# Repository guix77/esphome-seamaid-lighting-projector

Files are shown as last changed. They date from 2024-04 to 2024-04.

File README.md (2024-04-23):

# ESPHome remote for SeaMAID lighting projector

## Features

+ Turn on / off the light
+ Change the lightning mode

## Hardware

+ D1 mini ESP8266
+ stx882 (433Mhz transmitter)

Connect:
+ D1 ground to stx ground
+ D1 5V to stx VIN
+ D1 D4 (GPI02) to stx DATA

## Software

Create a new ESPHome with the following code: [pool-light.yaml](pool-light.yaml) 

## Case

### Box

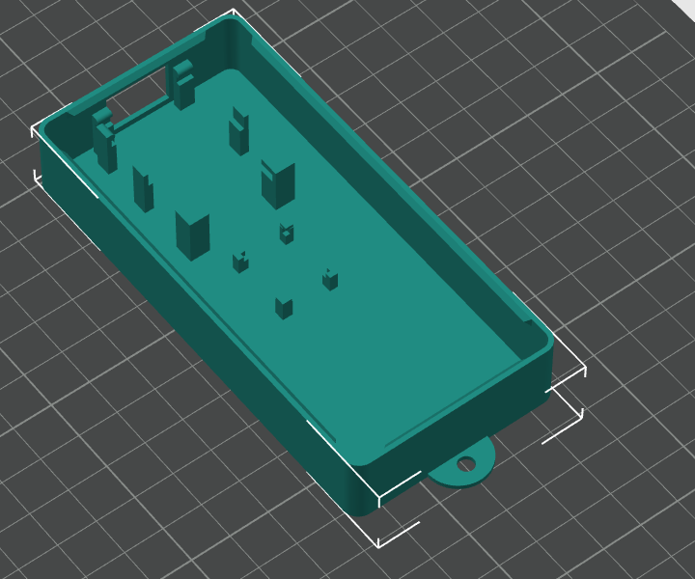
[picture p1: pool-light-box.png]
pool-light-box


[pool-light-box.stl](pool-light-box.stl)

In the box, the big mount is for the ESP and the small for the stx.

### Top

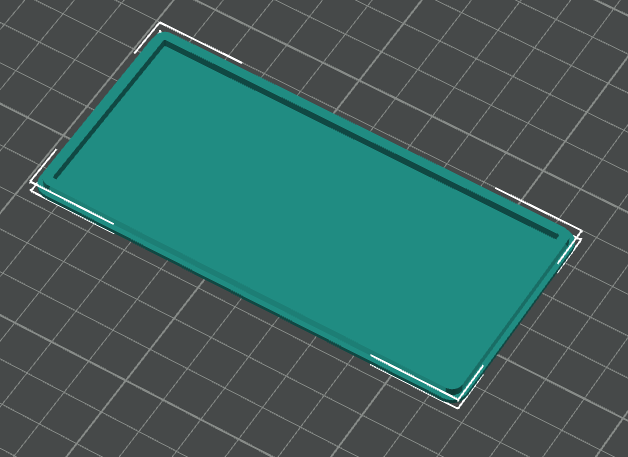
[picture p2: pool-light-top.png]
pool-light-top


[pool-light-top.stl](pool-light-top.stl)

### Photo

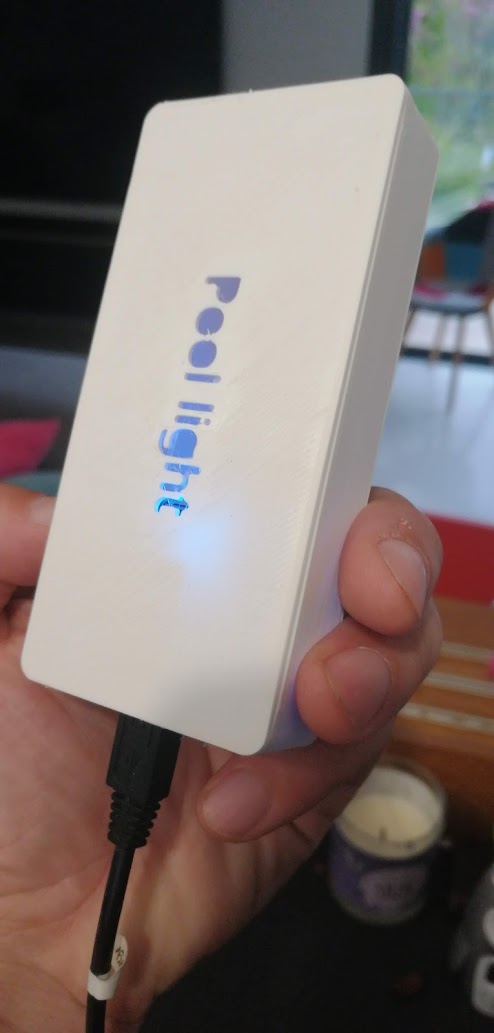
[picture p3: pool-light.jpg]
pool-light


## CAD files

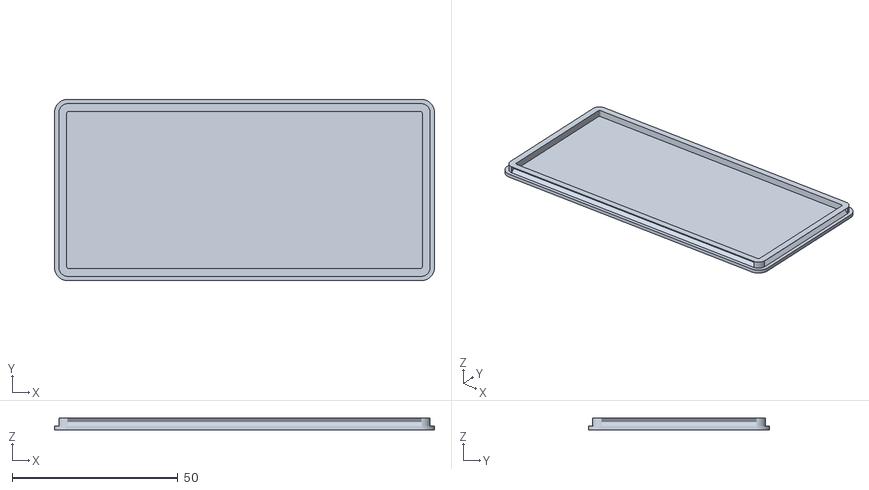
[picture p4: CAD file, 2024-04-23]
pool-light-top.stl
114.8 x 54.8 x 3.60

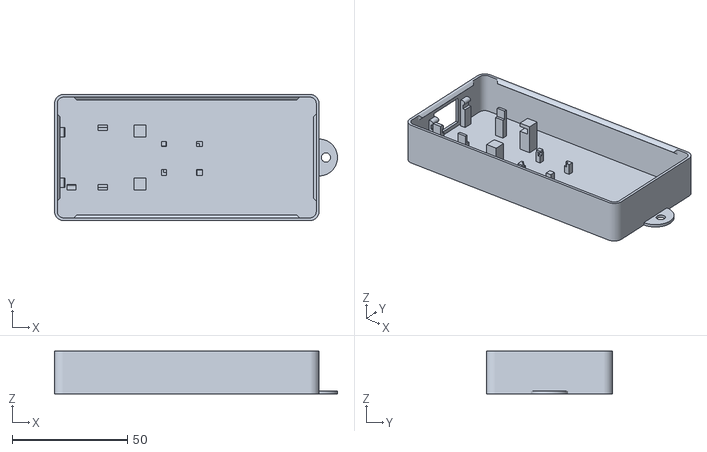
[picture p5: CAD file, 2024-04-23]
pool-light-box.stl
122.8 x 54.8 x 18.6

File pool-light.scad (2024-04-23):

use <ESPModels.scad>
use <sensorClip.scad>
use <wemos_d1_mini_clip.scad>

wemos_d1_offset = 10;
sensorWidth = 12;
sensorLength = 15;


// Which one would you like to see?
//part = "both"; // [box:Box only, top: Top cover only, both: Box and top cover]
part = "box";

// Size of your printer's nozzle in mm
nozzle_size = 0.4;

// Number of walls the print should have
number_of_walls = 3; // [1:5]

// Tolerance (use 0.2 for FDM)
tolerance = 0.2; // [0.1:0.1:0.4]

// Outer x dimension in mm
x=110+2*number_of_walls*nozzle_size+2*3*nozzle_size;

// Outer y dimension in mm
y=50+2*number_of_walls*nozzle_size+2*3*nozzle_size;

// Outer z dimension in mm
z=15+2*number_of_walls*nozzle_size+2*3*nozzle_size;

// Radius for rounded corners in mm
radius=4; // [1:20]

/* Hidden */
$fn=100;

wall_thickness=nozzle_size*number_of_walls;
hook_thickness = 3*nozzle_size;

top_cover_wall_thickness = hook_thickness + wall_thickness;

module bottom_box () {
    difference(){
        // Solid box
        linear_extrude(z-wall_thickness){
            minkowski(){
                square([x-radius*2,y-radius*2], center=true);
                circle(radius);
            }
        }
        
        // Hollow out
        translate([0,0,wall_thickness]) linear_extrude(z){
            minkowski(){
                square([x-radius*2-wall_thickness*2+wall_thickness*2,y-radius*2-wall_thickness*2+wall_thickness*2], center=true);
                circle(radius-wall_thickness);
            }
        }
        translate([-45, 11.5, 10]) {
            rotate([0, 0, -90]) {
                //WemosD1M(pins = 0, atorg = 2);
                translate([0, -6/2,2.5]) {
                    WemosD1M_USBLocate(atorg = 2)
                    translate([0, 6/2, 2.5]) {
                        cube([6.87+10, 6, 1.85+10], center=true);
                    }
                }
            }
        }
    }
    // D1 mini model.
    translate([-45, 11.5, 10]) {
        rotate([0, 0, -90]) {
            //WemosD1M(pins = 0, atorg = 2);
        }
    }
    // D1 mini clips.
    translate([-19, 13, wemos_d1_offset]) {
        rotate([0, 0, 180]) {
            wemos_d1_mini_clip(offset = wemos_d1_offset);
        }
    }
    // Sensor clip.
    translate([-11, 7, 0]) {
        rotate([0, 0, -90]) {
            sensorClip(sensorWidth, sensorLength, wall_thickness, 0.5);
        }
    }
    left_hook(); // left hook
    rotate([180,180,0]) left_hook(); // right hook
    front_hook(); // front hook
    rotate([180,180,0]) front_hook(); // back hook
    // TODO: hooks on the other two sides
    // Fixation.
    translate([x / 2, 0, 0]) {
        difference() {
            cylinder(h = wall_thickness, r = 8);
            translate([3, 0, 0]) {
                cylinder(h = wall_thickness + 0.01, r = 2);
            }
        }
    }
}

module left_hook () {
    
    translate([(x-2*wall_thickness)/2,-y/2+radius*2,z-wall_thickness]) rotate([0,90,90]) {
        difference(){
            linear_extrude(y-2*radius*2){
    polygon(points=[[0,0],[2*hook_thickness,0],[hook_thickness,hook_thickness]]);
        }
             translate([hook_thickness, hook_thickness, 0]) rotate([45,0,0]) cube(2*hook_thickness, center=true);
             translate([hook_thickness, hook_thickness, y-2*radius*2]) rotate([45,0,0]) cube(2*hook_thickness, center=true);        
        }
    }
}
    

module front_hook () {
    translate([(-x+4*radius)/2,-y/2+wall_thickness,z-wall_thickness]) rotate([90,90,90]) {
        difference(){
        linear_extrude(x-2*radius*2){
    polygon(points=[[0,0],[2*hook_thickness,0],[hook_thickness,hook_thickness]]);
    }
             translate([hook_thickness, hook_thickness, 0]) rotate([45,0,0]) cube(2*hook_thickness, center=true);
             translate([hook_thickness, hook_thickness, x-2*radius*2]) rotate([45,0,0]) cube(2*hook_thickness, center=true);
        }
    }
}


module right_grove () {
    translate([-tolerance/2+(x-2*wall_thickness)/2,-y/2+radius,wall_thickness+hook_thickness*2]) rotate([0,90,90]) linear_extrude(y-2*radius){
    polygon(points=[[0,0],[2*hook_thickness,0],[hook_thickness,hook_thickness]]);
    }
}


module front_grove () {
    translate([(-x+2*radius)/2,-y/2+wall_thickness+tolerance/2,wall_thickness+hook_thickness*2]) rotate([90,90,90]) linear_extrude(x-2*radius){
    polygon(points=[[0,0],[2*hook_thickness,0],[hook_thickness,hook_thickness]]);
    }
}

module top_cover () {

    // Top face
    linear_extrude(wall_thickness){
        minkowski(){
            square([x-radius*2,y-radius*2], center=true);
            circle(radius);
        }
    }
    
    difference(){
        // Wall of top cover
        linear_extrude(wall_thickness+hook_thickness*2){
            minkowski(){
                square([x-radius*2-wall_thickness*2-tolerance+wall_thickness*2,y-radius*2-wall_thickness*2-tolerance+wall_thickness*2], center=true);
                circle(radius-wall_thickness);
            }
        }
        
        // Hollow out
        // TODO: If radius is very small, still hollow out

        translate([0,0,wall_thickness]) linear_extrude(z){
            minkowski(){
                square([x-radius*2-wall_thickness*2-2*top_cover_wall_thickness-tolerance+wall_thickness*2+top_cover_wall_thickness*2,y-radius*2-wall_thickness*2-2*top_cover_wall_thickness-tolerance+wall_thickness*2+top_cover_wall_thickness*2], center=true);
            circle(radius-wall_thickness-top_cover_wall_thickness);
            }
        }
    right_grove();
    rotate([180,180,0]) right_grove();
    front_grove();
    rotate([180,180,0])  front_grove();
    }
  

}

// left_hook();
print_part();

module print_part() {
	if (part == "box") {
		bottom_box();
	} else if (part == "top") {
		top_cover();
	} else if (part == "both") {
		both();
	} else {
		both();
	}
}

module both() {
	translate([0,-(y/2+wall_thickness),0]) bottom_box();
    translate([0,+(y/2+wall_thickness),0]) top_cover();
}

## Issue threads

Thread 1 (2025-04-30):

Esphome Projecteur BWT

nadlio, 2025-04-30:
Bonjour ,
j'ai un projecteur BWT avec une telecommande 433 qui a le meme visuel que le Seamaid .
Je me suis dit , super je vais pouvoir transferer le code dans un esp pour avoir un pilotage en parrallele avec Esphome .

Non cela ne fonctionne pas car les codes sont différents et le pulse lenght aussi .

J'ai donc fait un montage avec un arduino pour récuperer les codes .

Donc voici mon fichier yaml qui fonctionne avec les projecteur BWT ou Procopi  (il y a aussi ajout d'envoi d'info en MQTT)

substitutions:
  name: "pool-light"
  friendly_name: Pool light

esphome:
  name: ${name}
  friendly_name: ${friendly_name}

esp8266:
  board: d1_mini

logger:

ota:
  - platform: esphome
    password: "esphome"

wifi:
  ssid: !secret wifi_ssid
  password: !secret wifi_password

web_server:
  port: 80

mqtt:
  broker: 192.168.0.76
  port: 1883
  username: ""
  password: ""

remote_transmitter:
  pin: GPIO2
  carrier_duty_percent: 100%

output:
  - platform: template
    id: pool_light
    type: binary
    write_action:
      - delay: 0s

light:
  - platform: binary
    name: "Pool Light"
    output: pool_light
    on_turn_on:
      - remote_transmitter.transmit_rc_switch_raw:
          code: '011011100001011110000000'
          protocol:
            pulse_length: 640
          repeat:
            times: 10
            wait_time: 0ms
    on_turn_off:
      - remote_transmitter.transmit_rc_switch_raw:
          code: '011011100001011110001111'
          protocol:
            pulse_length: 640
          repeat:
            times: 10
            wait_time: 0ms

select:
  - platform: template
    name: "Pool light mode"
    id: pool_light_mode
    options:
      - "Change en continu (lent)"
      - "Change en continu (rapide)"
      - "Change en continu (avec sauts)"
      - "Change toutes les 5s"
      - "Change toutes les 15s"
      - "Blanc"
      - "Bleu"
      - "Cyan"
      - "Cyan clair"
      - "Vert clair"
      - "Vert"
      - "Vert - jaune"
      - "Jaune"
      - "Jaune doré"
      - "Rouge"
      - "Violet"
    optimistic: true
    on_value:
      then:
        - if:
            condition:
              lambda: |-
                return id(pool_light_mode).state == "Change en continu (lent)";
            then:
              - remote_transmitter.transmit_rc_switch_raw:
                  code: '011011100001011100011011'
                  protocol:
                    pulse_length: 640
                  repeat:
                    times: 10
                    wait_time: 0ms
        - if:
            condition:
              lambda: |-
                return id(pool_light_mode).state == "Change en continu (rapide)";
            then:
              - remote_transmitter.transmit_rc_switch_raw:
                  code: '011011100001011100011101'
                  protocol:
                    pulse_length: 640
                  repeat:
                    times: 10
                    wait_time: 0ms
        - if:
            condition:
              lambda: |-
                return id(pool_light_mode).state == "Change en continu (avec sauts)";
            then:
              - remote_transmitter.transmit_rc_switch_raw:
                  code: '011011100001011100011110'
                  protocol:
                    pulse_length: 640
                  repeat:
                    times: 10
                    wait_time: 0ms
        - if:
            condition:
              lambda: |-
                return id(pool_light_mode).state == "Change toutes les 5s";
            then:
              - remote_transmitter.transmit_rc_switch_raw:
                  code: '011011100001011100011111'
                  protocol:
                    pulse_length: 640
                  repeat:
                    times: 10
                    wait_time: 0ms
        - if:
            condition:
              lambda: |-
                return id(pool_light_mode).state == "Change toutes les 15s";
            then:
              - remote_transmitter.transmit_rc_switch_raw:
                  code: '011011100001011100011011'
                  protocol:
                    pulse_length: 640
                  repeat:
                    times: 10
                    wait_time: 0ms
        - if:
            condition:
              lambda: |-
                return id(pool_light_mode).state == "Blanc";
            then:
              - remote_transmitter.transmit_rc_switch_raw:
                  code: '011011100001011100100000'
                  protocol:
                    pulse_length: 640
                  repeat:
                    times: 10
                    wait_time: 0ms
        - if:
            condition:
              lambda: |-
                return id(pool_light_mode).state == "Bleu";
            then:
              - remote_transmitter.transmit_rc_switch_raw:
                  code: '011011100001011100100001'
                  protocol:
                    pulse_length: 640
                  repeat:
                    times: 10
                    wait_time: 0ms
        - if:
            condition:
              lambda: |-
                return id(pool_light_mode).state == "Cyan";
            then:
              - remote_transmitter.transmit_rc_switch_raw:
                  code: '011011100001011100100010'
                  protocol:
                    pulse_length: 640
                  repeat:
                    times: 10
                    wait_time: 0ms
        - if:
            condition:
              lambda: |-
                return id(pool_light_mode).state == "Cyan clair";
            then:
              - remote_transmitter.transmit_rc_switch_raw:
                  code: '011011100001011100100011'
                  protocol:
                    pulse_length: 640
                  repeat:
                    times: 10
                    wait_time: 0ms
        - if:
            condition:
              lambda: |-
                return id(pool_light_mode).state == "Vert clair";
            then:
              - remote_transmitter.transmit_rc_switch_raw:
                  code: '011011100001011100100100'
                  protocol:
                    pulse_length: 640
                  repeat:
                    times: 10
                    wait_time: 0ms
        - if:
            condition:
              lambda: |-
                return id(pool_light_mode).state == "Vert";
            then:
              - remote_transmitter.transmit_rc_switch_raw:
                  code: '011011100001011100100101'
                  protocol:
                    pulse_length: 640
                  repeat:
                    times: 10
                    wait_time: 0ms
        - if:
            condition:
              lambda: |-
                return id(pool_light_mode).state == "Vert - jaune";
            then:
              - remote_transmitter.transmit_rc_switch_raw:
                  code: '011011100001011100100110'
                  protocol:
                    pulse_length: 640
                  repeat:
                    times: 10
                    wait_time: 0ms
        - if:
            condition:
              lambda: |-
                return id(pool_light_mode).state == "Jaune";
            then:
              - remote_transmitter.transmit_rc_switch_raw:
                  code: '011011100001011100100111'
                  protocol:
                    pulse_length: 640
                  repeat:
                    times: 10
                    wait_time: 0ms
        - if:
            condition:
              lambda: |-
                return id(pool_light_mode).state == "Jaune doré";
            then:
              - remote_transmitter.transmit_rc_switch_raw:
                  code: '011011100001011100101000'
                  protocol:
                    pulse_length: 640
                  repeat:
                    times: 10
                    wait_time: 0ms
        - if:
            condition:
              lambda: |-
                return id(pool_light_mode).state == "Rouge";
            then:
              - remote_transmitter.transmit_rc_switch_raw:
                  code: '011011100001011100101001'
                  protocol:
                    pulse_length: 640
                  repeat:
                    times: 10
                    wait_time: 0ms
        - if:
            condition:
              lambda: |-
                return id(pool_light_mode).state == "Violet";
            then:
              - remote_transmitter.transmit_rc_switch_raw:
                  code: '011011100001011100101010'
                  protocol:
                    pulse_length: 640
                  repeat:
                    times: 10
                    wait_time: 0ms ``

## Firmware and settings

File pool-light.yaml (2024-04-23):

substitutions:
  name: "pool-light"
  friendly_name: Pool light

esphome:
  name: ${name}
  friendly_name: ${friendly_name}

esp8266:
  board: esp01_1m

logger:

api:
  encryption:
    key: "REPLACE_ME"

ota:

wifi:
  ssid: !secret wifi_ssid
  password: !secret wifi_password

remote_transmitter:
  pin: GPIO2
  carrier_duty_percent: 100%

output:
  - platform: template
    id: pool_light
    type: binary
    write_action:
      - delay: 0s
          
light:
  - platform: binary
    name: "Pool Light"
    output: pool_light
    on_turn_on:
      - remote_transmitter.transmit_rc_switch_raw:
          code: '101100001101001010000000'
          protocol:
            pulse_length: 900
          repeat:
            times: 10
            wait_time: 0ms
    on_turn_off:
      - remote_transmitter.transmit_rc_switch_raw:
          code: '101100001101001010001111'
          protocol:
            pulse_length: 900
          repeat:
            times: 10
            wait_time: 0ms

select:
  - platform: template
    name: "Pool light mode"
    id: pool_light_mode
    options:
      - "Change en continu (lent)"
      - "Change en continu (rapide)"
      - "Change en continu (avec sauts)"
      - "Change toutes les 5s"
      - "Change toutes les 15s"
      - "Blanc"
      - "Bleu"
      - "Cyan"
      - "Cyan clair"
      - "Vert clair"
      - "Vert"
      - "Vert - jaune"
      - "Jaune"
      - "Jaune doré"
      - "Rouge"
      - "Violet"
    optimistic: true 
    on_value:
      then:
        - if:
            condition:
              lambda: |-
                return id(pool_light_mode).state == "Change en continu (lent)";
            then:
              - remote_transmitter.transmit_rc_switch_raw:
                  code: '101100001101001000011011'
                  protocol:
                    pulse_length: 900
                  repeat:
                    times: 10
                    wait_time: 0ms
        - if:
            condition:
              lambda: |-
                return id(pool_light_mode).state == "Change en continu (rapide)";
            then:
              - remote_transmitter.transmit_rc_switch_raw:
                  code: '101100001101001000011100'
                  protocol:
                    pulse_length: 900
                  repeat:
                    times: 10
                    wait_time: 0ms
        - if:
            condition:
              lambda: |-
                return id(pool_light_mode).state == "Change en continu (avec sauts)";
            then:
              - remote_transmitter.transmit_rc_switch_raw:
                  code: '101100001101001000011101'
                  protocol:
                    pulse_length: 900
                  repeat:
                    times: 10
                    wait_time: 0ms
        - if:
            condition:
              lambda: |-
                return id(pool_light_mode).state == "Change toutes les 5s";
            then:
              - remote_transmitter.transmit_rc_switch_raw:
                  code: '101100001101001000011110'
                  protocol:
                    pulse_length: 900
                  repeat:
                    times: 10
                    wait_time: 0ms
        - if:
            condition:
              lambda: |-
                return id(pool_light_mode).state == "Change toutes les 15s";
            then:
              - remote_transmitter.transmit_rc_switch_raw:
                  code: '101100001101001000011111'
                  protocol:
                    pulse_length: 900
                  repeat:
                    times: 10
                    wait_time: 0ms
        - if:
            condition:
              lambda: |-
                return id(pool_light_mode).state == "Blanc";
            then:
              - remote_transmitter.transmit_rc_switch_raw:
                  code: '101100001101001000100000'
                  protocol:
                    pulse_length: 900
                  repeat:
                    times: 10
                    wait_time: 0ms
        - if:
            condition:
              lambda: |-
                return id(pool_light_mode).state == "Bleu";
            then:
              - remote_transmitter.transmit_rc_switch_raw:
                  code: '101100001101001000100001'
                  protocol:
                    pulse_length: 900
                  repeat:
                    times: 10
                    wait_time: 0ms
        - if:
            condition:
              lambda: |-
                return id(pool_light_mode).state == "Cyan";
            then:
              - remote_transmitter.transmit_rc_switch_raw:
                  code: '101100001101001000100010'
                  protocol:
                    pulse_length: 900
                  repeat:
                    times: 10
                    wait_time: 0ms
        - if:
            condition:
              lambda: |-
                return id(pool_light_mode).state == "Cyan clair";
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
